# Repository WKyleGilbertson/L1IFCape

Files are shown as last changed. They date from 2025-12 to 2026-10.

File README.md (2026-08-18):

L1IFCape

===

This project (hardware and software) is licensed under CERN-OHL-S and GPLv3 for open-source, academic, and personal use. Commercial licensing is available. If you wish to integrate this receiver into a closed-source, proprietary, or commercial product without the reciprocal open-source obligations, please email contact@navstargps.us to purchase a commercial license.

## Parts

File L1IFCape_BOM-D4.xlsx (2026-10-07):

Reference | Qty | Value | Footprint | DNP | MFR | MP | MPN | VPN | Vendor | Description
C1 | 1 | 1F | L1IF:KR5R5C105R |  | Eaton | KW-5R5C334-R | KR-5R5C105-R | 283-KR-5R5C105-R-ND | DigiKey | Supercapacitors / Ultracapacitors CAP 0.33F 5.5V EDLC Coin Cell Cylind
C2,C3,C6,C7,C15,C27,C28,C35 | 8 | 1.0 uF | L1IF:C_0603_1608Metric |  | Murata |  | GCM188R71C105KA64D | 490-5241-1-ND | DigiKey | CAP CER 1UF 16V X7R 0603
C4,C5,C13,C21,C22,C23,C24,C25,C26 | 9 | 100 nF | L1IF:C_0603_1608Metric |  | Kemet |  | C0603C104K5RACAUTO | 399-6856-1-ND | DigiKey | CAP CER 0.1UF 50V X7R 0603
C8,C9,C14 | 3 | 10 nF | L1IF:C_0603_1608Metric |  | Kemet |  | C0603C103F3GECAUTO | 399-C0603C103F3GECAUTOCT-ND | DigiKey | CAP CER 10000PF 25V C0G/NP0 0603
C10,C11,C18 | 3 | 470 pF | L1IF:C_0603_1608Metric |  | Murata |  | GCM1885C2A471FA16D | 490-GCM1885C2A471FA16DCT-ND | DigiKey | CAP CER 470PF 100V C0G/NP0 0603
C12,C16,C20,C36,C37,C38,C39 | 7 | 100 pF | L1IF:C_0603_1608Metric |  | Murata |  | GCM1885C2A101FA16D | 490-GCM1885C2A101FA16DCT-ND | DigiKey | CAP CER 100PF 100V C0G/NP0 0603
C17 | 1 | 27 pF | L1IF:C_0603_1608Metric |  | Kemet |  | C0603C270F3HACAUTO | 399-C0603C270F3HACAUTOCT-ND | DigiKey | CAP CER 0603 27PF 25V ULTRA STAB
C19 | 1 | 470 pF | L1IF:C_0603_1608Metric | 470 pF | Murata |  | GCM1885C2A471FA16D | 490-GCM1885C2A471FA16DCT-ND | DigiKey | GCM1885C2A471FA16D
C29,C30 | 2 | 10 nF | L1IF:C_0603_1608Metric | 10 nF | Kemet |  | C0603C103F3GECAUTO | 399-C0603C103F3GECAUTOCT-ND | DigiKey | CAP CER 10000PF 25V C0G/NP0 0603
C31,C33 | 2 | 4.7 uF | L1IF:C_0805_2012Metric |  | Kemet |  | C0805C475J8RACAUTO | 399-15708-1-ND | DigiKey | CAP CER 4.7UF 10V X7R 0805
C32,C34 | 2 | 100 nF | L1IF:C_0805_2012Metric |  | Kemet |  | C0805C104K8RACTU | 399-C0805C104K8RACTUCT-ND | DigiKey | CAP CER 0.1UF 10V X7R 0805
D1,D2 | 2 | TPD1E01B04 | L1IF:Texas_DPY0002A_0.6x1mm_P0.65mm |  | Texas Instruments |  | TPD1E01B04DPYRQ1 | 296-TPD1E01B04DPYRQ1CT-ND | DigiKey | TPD1E01B04 Single-Channel ESD Protection Diode
FB1,FB2 | 2 | Ferrite_Bead | L1IF:C_0805_2012Metric |  | Murata |  | BLM21AG102SZ1D | 490-14399-1-ND | DigiKey | FERRITE BEAD 1 KOHM 0805 1LN
J1 | 1 | RF_Shield_One_Piece | L1IF:Laird_Technologies_BMI-S-103_26.21x26.21mm |  | Laird |  | BMI-S-103 | 903-1008-1-ND | DigiKey | One-piece EMI RF shielding cabinet
J2 | 1 | SMA | L1IF:SMA_Amphenol_901-143_Horizontal |  | Amphenol RF |  | 901-143 | ARF1206-ND | DigiKey | coaxial connector (BNC, SMA, SMB, SMC, Cinch/RCA, ...)
J3 | 1 | MMCX | L1IF:MMCX_Molex_73415-1471_Vertical |  | Amphenol RF |  | 908-22106 | ARF1904-ND | DigiKey | CONN MMCX JACK STR 50 OHM PCB
L1 | 1 | 33 nH | L1IF:L_0603_1608Metric |  |  |  | LQG18HH33NJ00D | 490-14837-1-ND | DigiKey | FIXED IND 33NH 500MA 0.54OHM SMD
P8,P9 | 2 | BeagleBone_Black_Header | L1IF:PinHeader_2x23_P2.54mm_Vertical |  | Samtec Inc. |  | SSQ-123-23-G-D | 612-SSQ-123-23-G-D-ND | DigiKey | CONN RCPT 46POS 0.1 GOLD PCB
R1,R3,R4,R6,R15 | 5 | 0 | L1IF:R_0603_1608Metric |  | Panasonic |  | ERJ-3GEY0R00V | P0.0GCT-ND | DigiKey | RES SMD 0 OHM JUMPER 1/10W 0603
R2,R5,R16 | 3 | 0 | L1IF:R_0603_1608Metric | 0 | Panasonic |  | ERJ-3GEY0R00V | P0.0GCT-ND | DigiKey | RES SMD 0 OHM JUMPER 1/10W 0603
R7,R8,R9,R11,R12,R18,R19,R20,R21,R22 | 10 | 33 | L1IF:R_0603_1608Metric |  | Panasonic |  | ERJ-3EKF33R0V | P33.0HCT-ND | Digikey | RES SMD 33 OHM 1% 1/10W 0603
R10 | 1 | 20k | L1IF:R_0603_1608Metric |  | Panasonic |  | ERJ-3EKF2002V | P20.0KHCT-ND | DigiKey | RES SMD 20K OHM 1% 1/10W 0603
R13,R14 | 2 | 2k | L1IF:R_0603_1608Metric |  | Panasonic |  | ERJ-3EKF2001V | P2.00KHCT-ND | DigiKey | RES SMD 2K OHM 1% 1/10W 0603
R17 | 1 | 10k | L1IF:R_0603_1608Metric |  | Panasonic |  | ERJ-3EKF1002V | P10.0KHCT-ND | DigiKey | RES SMD 10K OHM 1% 1/10W 0603
TP1 | 1 | ANTFLAG | L1IF:TestPoint_THTPad_D1.5mm_Drill0.7mm |  |  |  |  |  |  | test point
TP2 | 1 | LD | L1IF:TestPoint_THTPad_D1.5mm_Drill0.7mm |  |  |  |  |  |  | test point
TP3 | 1 | ~{SHDN} | L1IF:TestPoint_THTPad_D1.5mm_Drill0.7mm |  |  |  |  |  |  | test point
TP4 | 1 | CP | L1IF:TestPoint_Pad_D1.0mm |  |  |  |  |  |  | test point
TP5 | 1 | BBClk | L1IF:TestPoint_THTPad_D1.5mm_Drill0.7mm |  |  |  |  |  |  | test point
U1 | 1 | 24CS256 | L1IF:SOT-23-5 |  | Microchip Technology |  | 24CS256T-I/OT | 150-24CS256T-I/OTCT-ND | DigiKey | IC EEPROM 256KBIT I2C SOT23-5
U2 | 1 | MAX2769BETI+T | L1IF:QFN-28_EP_5.63x5.63_Pitch0.5mm |  | Maxim / Analog |  | MAX2769BETI/V+T | 175-MAX2769BETI/V+TCT-ND | DigiKey | RF RCVR GPS 1575.42MHZ 28TQFN
U3 | 1 | MAX31343ETAY+T | L1IF:MAX31343_TDFN |  | Maxim / Analog |  | MAX31343ETAY+T | 175-MAX31343ETAY+TCT-ND | DigiKey | ACCURATE/ROBUST RTC WITH INTEGRA
U4,U5 | 2 | TPS717285DCK | L1IF:TPS717285DCK |  | Texas Instruments |  | TPS717285DCK | 296-32541-1-ND | DigiKey | IC REG LINEAR 2.85V 150MA SC70-5
X1 | 1 | SIT5155 | L1IF:10L_CQFN |  | SiTime |  | SiT5155AICFKG28IT-16.367667 |  | SiTime | MEMS OSC DCTCXO 16.367667 MHZ
X2 | 1 | QPQ1060 | L1IF:QPQ1060_1.4x1.2 |  | Qorvo |  | QPQ1060SR | 2312-QPQ1060SRCT-ND | DigiKey | Bandpass Filter, 1090MHz, SAW filter 6-pin

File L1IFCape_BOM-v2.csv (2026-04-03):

Reference | Value | Datasheet | Footprint | Qty | DNP | MFR | MPN | Manufacturer | Vendor | Vendor PN | VPN
C1 | 1F | https://www.eaton.com/content/dam/eaton/products/electronic-components/resources/data-sheet/eaton-kr-supercapacitors-coin-cells-data-sheet.pdf | L1IF:KR5R5C105R | 1 |  | Eaton | KR-5R5C105-R | Eaton | DigiKey | 283-KR-5R5C105-R-ND | 283-KR-5R5C105-R-ND
C2,C3,C6,C7,C15,C27,C28,C35 | 1.0 uF |  | L1IF:C_0603_1608Metric | 8 |  |  | GCM188R71C105KA64D | Murata | DigiKey | 490-5241-1-ND
C4,C5,C13,C21,C22,C23,C24,C25,C26 | 100 nF |  | L1IF:C_0603_1608Metric | 9 |  |  | C0603C104K5RACAUTO | Kemet | DigiKey | 399-6856-1-ND
C8,C9,C14,C16 | 10 nF |  | L1IF:C_0603_1608Metric | 4 |  |  | C0603C103F3GECAUTO | Kemet | DigiKey | 399-C0603C103F3GECAUTOCT-ND
C10,C11,C18 | 470 pF |  | L1IF:C_0603_1608Metric | 3 |  |  | GCM1885C2A471FA16D | Murata | DigiKey | 490-GCM1885C2A471FA16DCT-ND
C12,C20 | 100 pF |  | L1IF:C_0603_1608Metric | 2 |  |  | GCM1885C2A101FA16D | Murata | DigiKey | 490-GCM1885C2A101FA16DCT-ND
C17 | 27 pF |  | L1IF:C_0603_1608Metric | 1 |  |  | C0603C270F3HACAUTO | Kemet | DigiKey | 399-C0603C270F3HACAUTOCT-ND
C19 | NL |  | L1IF:C_0603_1608Metric | 1 | 470 pF |  | GCM1885C2A471FA16D | Murata | DigiKey | 490-GCM1885C2A471FA16DCT-ND
C29,C30 | NL |  | L1IF:C_0603_1608Metric | 2 | 10 nF
C31,C33 | 4.7 uF |  | L1IF:C_0805_2012Metric | 2 |  |  | C0805C475J8RACAUTO | Kemet | DigiKey | 399-15708-1-ND
C32,C34 | 100 nF |  | L1IF:C_0805_2012Metric | 2 |  |  | C0805C104K8RACTU | Kemet | DigiKey | 399-C0805C104K8RACTUCT-ND
D1,D2 | TPD1E01B04 | https://www.ti.com/product/TPD1E01B04 | L1IF:Texas_DPY0002A_0.6x1mm_P0.65mm | 2 |  | Texas Instruments | TPD1E01B04DPYRQ1 | Texas Instruments | DigiKey | 296-TPD1E01B04DPYRQ1CT-ND | 296-TPD1E01B04DPYRQ1CT-ND
FB1,FB2 | Ferrite_Bead | https://www.murata.com/en-us/products/en-us/products/productdata/8796749987870/QNFA9114.pdf | L1IF:C_0805_2012Metric | 2 |  |  | BLM21AG102SZ1D | Murata Electronics | DigiKey | 490-14399-1-ND
J1 | RF_Shield_One_Piece |  | L1IF:Laird_Technologies_BMI-S-103_26.21x26.21mm | 1 |  |  | BMI-S-103 | Laird Technologies EMI | DigiKey | 903-1008-1-ND
J2 | SMA |  | L1IF:SMA_Amphenol_901-143_Horizontal | 1 |  | Amphenol RF | 901-143 |  | DigiKey | ARF1206-ND
J3 | MMCX |  | L1IF:MMCX_Molex_73415-1471_Vertical | 1 |  | Amphenol RF | 908-22106 |  | DigiKey | ARF1904-ND
L1 | 33 nH | https://search.murata.co.jp/Ceramy/image/img/P02/JELF243B-9102.pdf | L1IF:L_0603_1608Metric | 1 |  |  | LQG18HH33NJ00D | Murata Electronics | DigiKey | 490-14837-1-ND | 490-14837-1-ND
P8,P9 | BeagleBone_Black_Header | https://mm.digikey.com/Volume0/opasdata/d220001/medias/docus/6129/ssq-1xx-xx-xxx-x-xx-xxx-xx-x-mkt.pdf | L1IF:PinHeader_2x23_P2.54mm_Vertical | 2 |  | Samtec Inc. | SSQ-123-02-G-D |  | DigiKey | SAM1185-23-ND
R1 | 20k |  | L1IF:R_0603_1608Metric | 1 |  |  | ERJ-3EKF2002V | Panasonic | DigiKey | P20.0KHCT-ND
R2,R3 | 2k |  | L1IF:R_0603_1608Metric | 2 |  | Panasonic | ERJ-3EKF2001V |  | DigiKey | P2.00KHCT-ND | P2.00KHCT-ND
R4 | 0 |  | L1IF:R_0603_1608Metric | 1 |  | Panasonic | ERJ-3GEY0R00V |  | DigiKey | P0.0GCT-ND | P0.0GCT-ND
R5 | NL |  | L1IF:R_0603_1608Metric | 1 | 0 | Panasonic | ERJ-3GEY0R00V |  | DigiKey | P0.0GCT-ND | P0.0GCT-ND
R6,R7,R8,R9,R10 | 10k |  | L1IF:R_0603_1608Metric | 5 |  | Panasonic | ERJ-3EKF1002V |  | DigiKey | P10.0KHCT-ND
TP1 | ANTFLAG |  | L1IF:TestPoint_Pad_D1.0mm | 1
TP2 | LD |  | L1IF:TestPoint_Pad_D1.0mm | 1
TP3 | ~{SHDN} |  | L1IF:TestPoint_Pad_D1.0mm | 1
TP4 | CP |  | L1IF:TestPoint_Pad_D1.0mm | 1
U1 | 24CS256 | https://www.microchip.com/en-us/product/24cs256 | L1IF:SOT-23-5 | 1 |  | Microchip Technology | 24CS256T-I/OT | Microchip Technology | DigiKey | 150-24CS256T-I/OTCT-ND | 150-24CS256T-I/OTCT-ND
U2 | MAX2769BETI+T | https://www.analog.com/media/en/technical-documentation/data-sheets/MAX2769B.pdf | L1IF:QFN-28_EP_5.63x5.63_Pitch0.5mm | 1 |  | Maxim / Analog | MAX2769BETI/V+T | Maxim / Analog | DigiKey | 175-MAX2769BETI/V+TCT-ND | 175-MAX2769BETI/V+TCT-ND
U3 | MAX31343ETAY+T | https://www.analog.com/media/en/technical-documentation/data-sheets/MAX31343.pdf | L1IF:MAX31343_TDFN | 1 |  | Maxim / Analog | MAX31343ETAY+T | Maxim / Analog | DigiKey | 175-MAX31343ETAY+TCT-ND | 175-MAX31343ETAY+TCT-ND
U4,U5 | TPS717285DCK | https://www.ti.com/lit/ds/symlink/tps717.pdf | L1IF:TPS717285DCK | 2 |  | Texas Instruments | TPS717285DCK | Texas Instruments | DigiKey | 296-32541-1-ND | 296-32541-1-ND
U6 | DS90LV012A | https://www.ti.com/lit/gpn/ds90lv012a | L1IF:SOT-23-5 | 1 |  | Texas Instruments | DS90LV012ATMFX/NOPB | Texas Instruments | DigiKey | 296-38706-1-ND | 296-38706-1-ND
X1 | SIT5156 | https://www.sitime.com/support/resource-library/datasheets/sit5156-datasheet | L1IF:10L_CQFN | 1 |  | SiTime | SIT5156AICFK-30N0-16.368000 | SiTime | DigiKey | 1473-SIT5156AICFK-30N0-16.368000-ND | 1473-SIT5156AICFK-30N0-16.368000-ND
X2 | QPQ1060 | https://www.qorvo.com/products/p/QPQ1060 | L1IF:QPQ1060_1.4x1.2 | 1 |  | Qorvo | QPQ1060SR | Qorvo | DigiKey | 2312-QPQ1060SRCT-ND | 2312-QPQ1060SRCT-ND

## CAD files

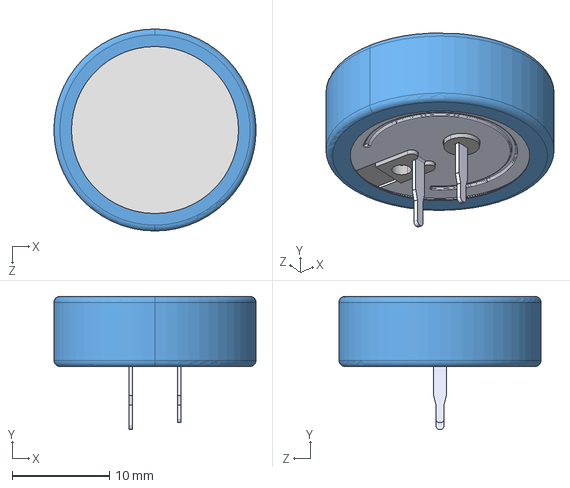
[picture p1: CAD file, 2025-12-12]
Parts/LIB_KR-5R5C105-R/KR-5R5C105-R/3D/KR-5R5C105-R.stp
20.8 x 13.7 x 20.8 mm

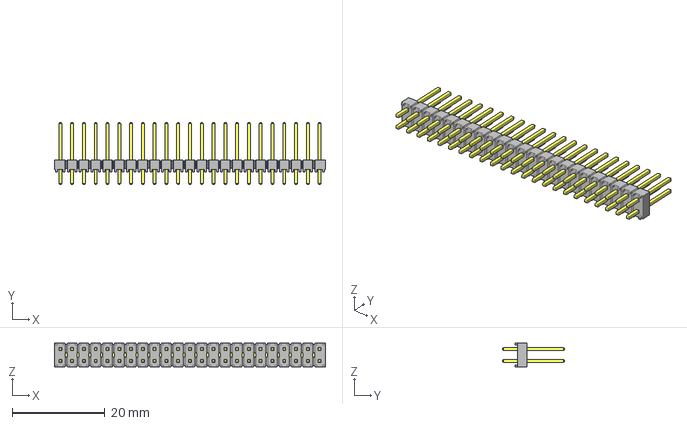
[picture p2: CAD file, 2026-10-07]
STEP/TSW-123-14-G-D.stp
58.4 x 13.5 x 5.08 mm
TSW-123-14-G-D_body
T-1S6-08-TSW-1-14-23-D

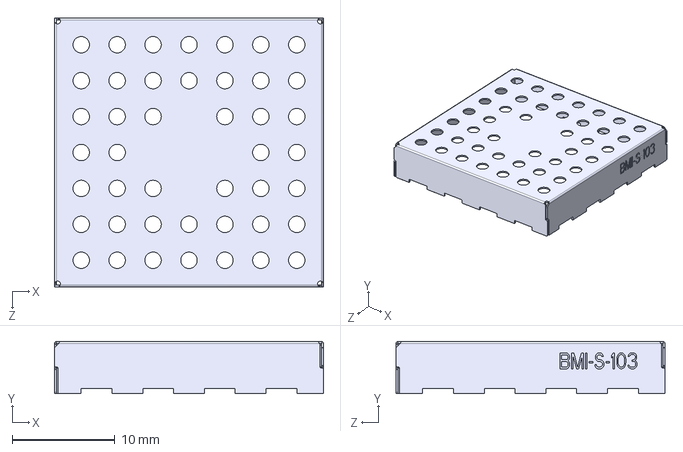
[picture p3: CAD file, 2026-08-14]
STEP/Laird-BMI-S-103-1.STEP
26.2 x 5.08 x 26.2 mm

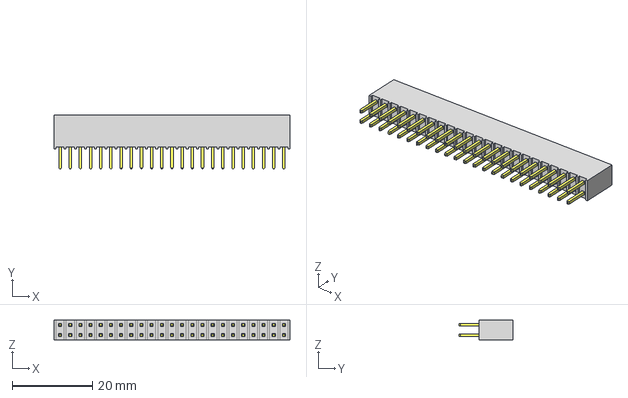
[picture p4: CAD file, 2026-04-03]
STEP/SSQ-123-02-G-D.stp
58.9 x 13.4 x 4.95 mm
T1SSQ-123-02-G-D
P2SSQ-123-02-G-D

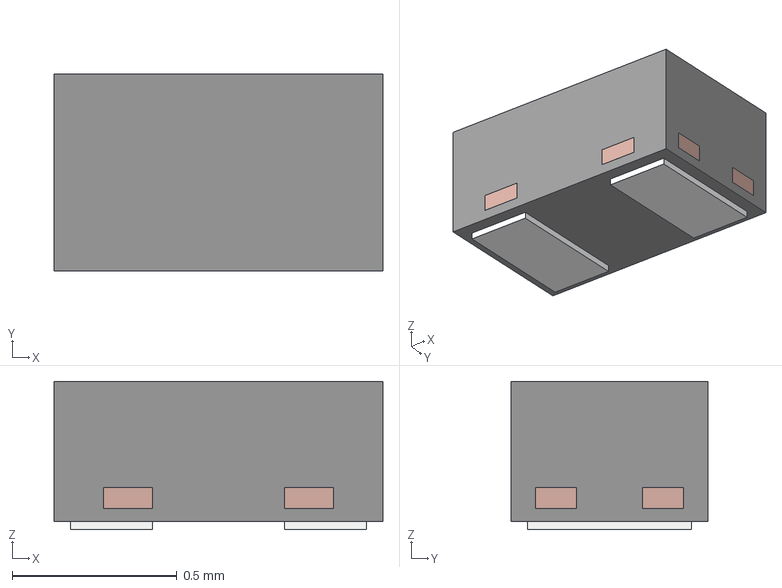
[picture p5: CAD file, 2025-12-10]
STEP/DPY0002A.stp
1.00 x 0.6 x 0.45 mm
BODY-SON
FRAME-DPY0002A

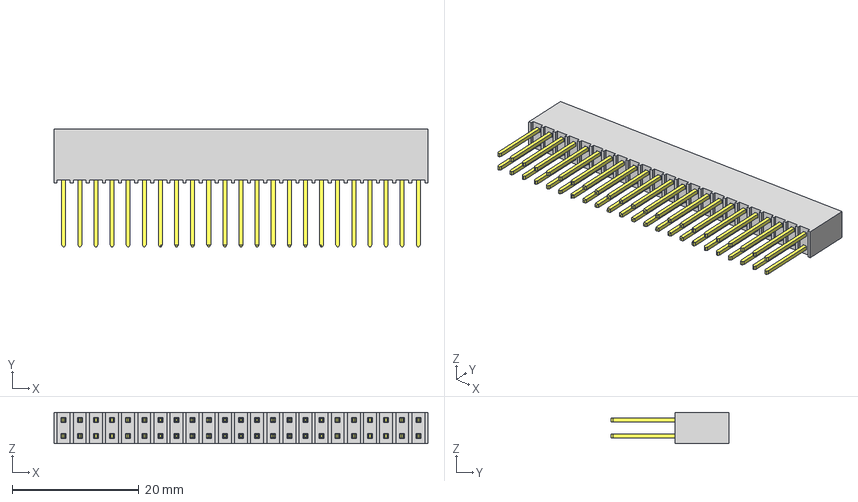
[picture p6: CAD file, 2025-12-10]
STEP/SSQ-123-03-G-D.stp
58.9 x 18.5 x 4.95 mm
T1SSQ-123-03-G-D
P2SSQ-123-03-G-D

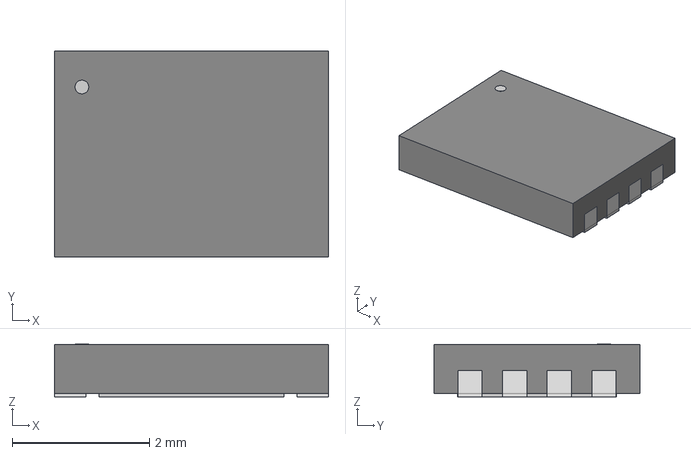
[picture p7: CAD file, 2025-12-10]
STEP/8-TDFN (3x4).step
3.99 x 3.00 x 0.765 mm

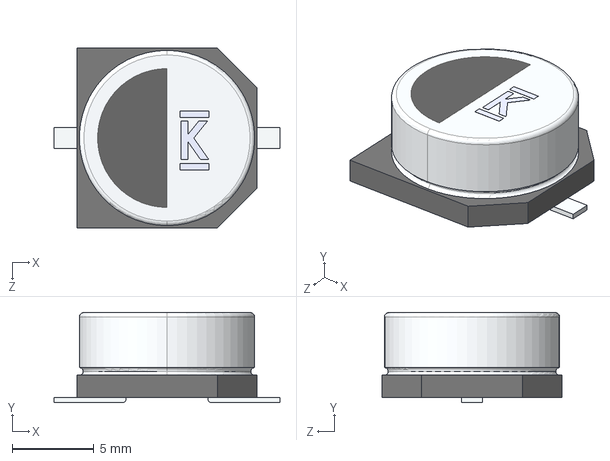
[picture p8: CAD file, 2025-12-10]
STEP/FCR0H104ZFTBR24.step
13.8 x 5.50 x 11.0 mm

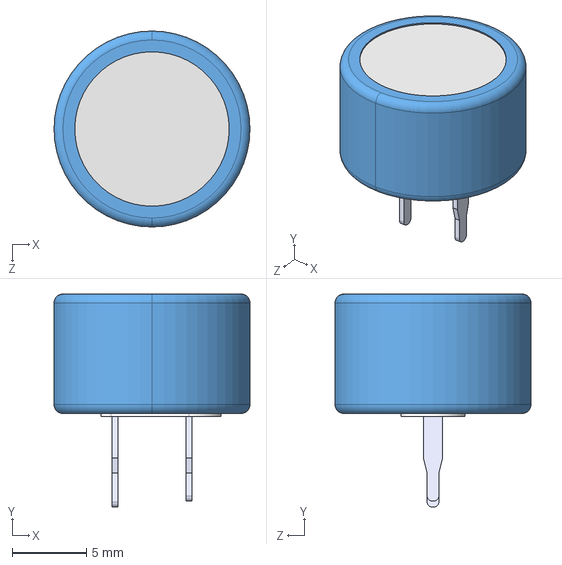
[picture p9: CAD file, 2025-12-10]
STEP/KW-5R5C334-R.stp
13.2 x 14.4 x 13.2 mm

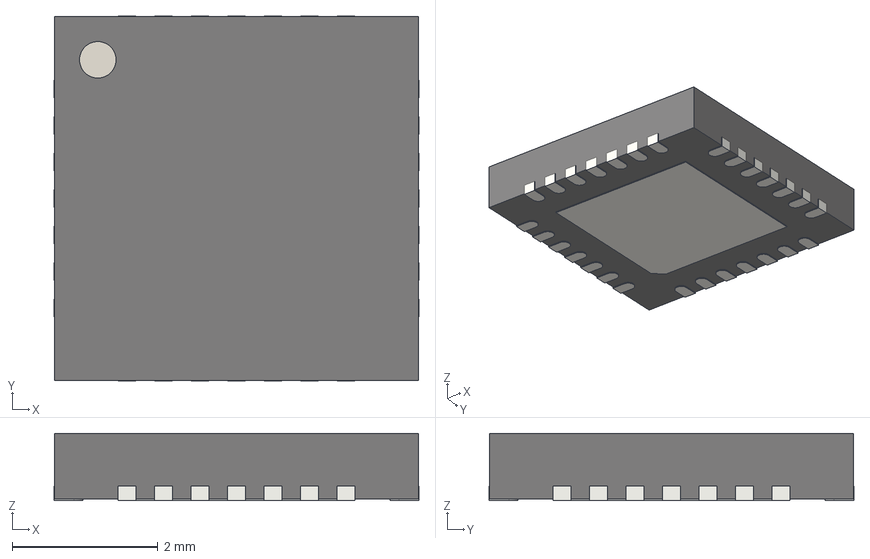
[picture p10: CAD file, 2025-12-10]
STEP/QFN-28-1EP_5x5mm_P0.5mm_EP3.35x3.35mm.step
5.00 x 5.00 x 0.92 mm

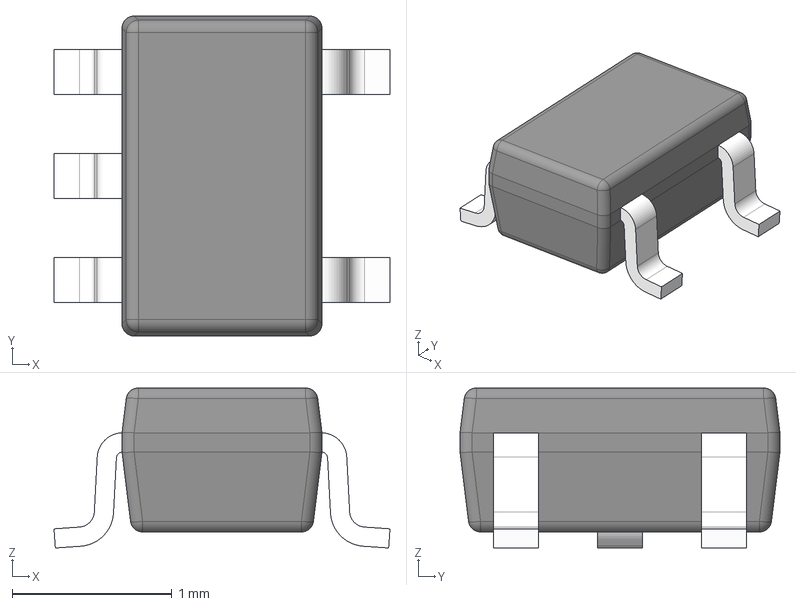
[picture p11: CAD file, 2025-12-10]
STEP/DCK0005A.stp
2.10 x 2.00 x 1.00 mm
BODY-SOT
LEAD-SOT x 5
PIN1-ID

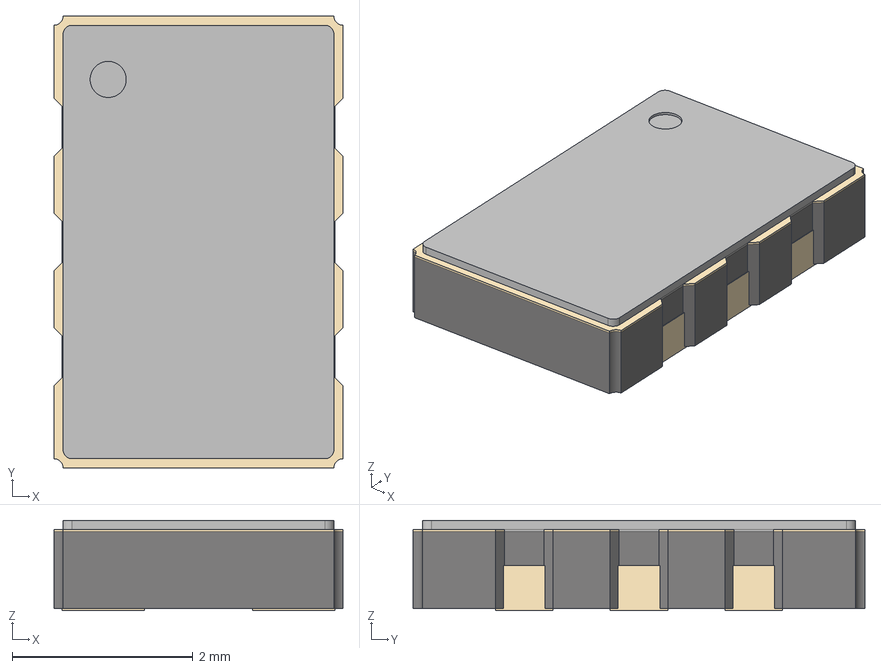
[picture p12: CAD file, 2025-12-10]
STEP/Oscillator_SMD_IDT_JS6-6_5.0x3.2mm_P1.27mm.step
3.20 x 5.00 x 1.00 mm

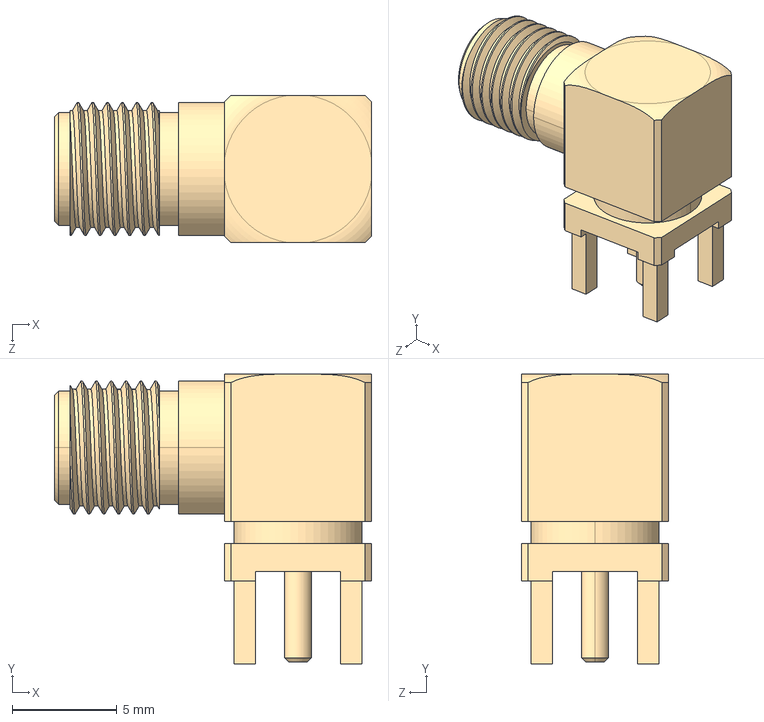
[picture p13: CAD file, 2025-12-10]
STEP/SMA-J-P-X-RA-TH1.step
15.1 x 13.8 x 7.00 mm

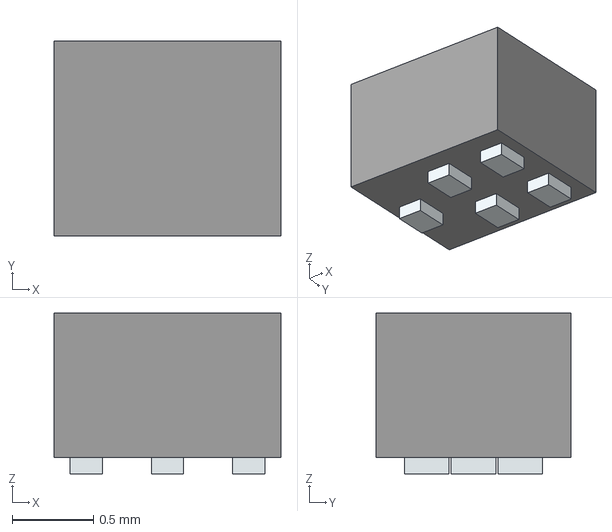
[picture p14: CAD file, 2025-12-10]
STEP/QPQ1060SR.stp
1.40 x 1.20 x 0.99 mm
Pins

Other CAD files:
Parts/LIB_KR-5R5C105-R/KR-5R5C105-R/Allegro/kr5r5c105r.psm
Parts/LIB_KR-5R5C105-R/KR-5R5C105-R/DEHDL/kr_5r5c105_r/chips/chips.prt

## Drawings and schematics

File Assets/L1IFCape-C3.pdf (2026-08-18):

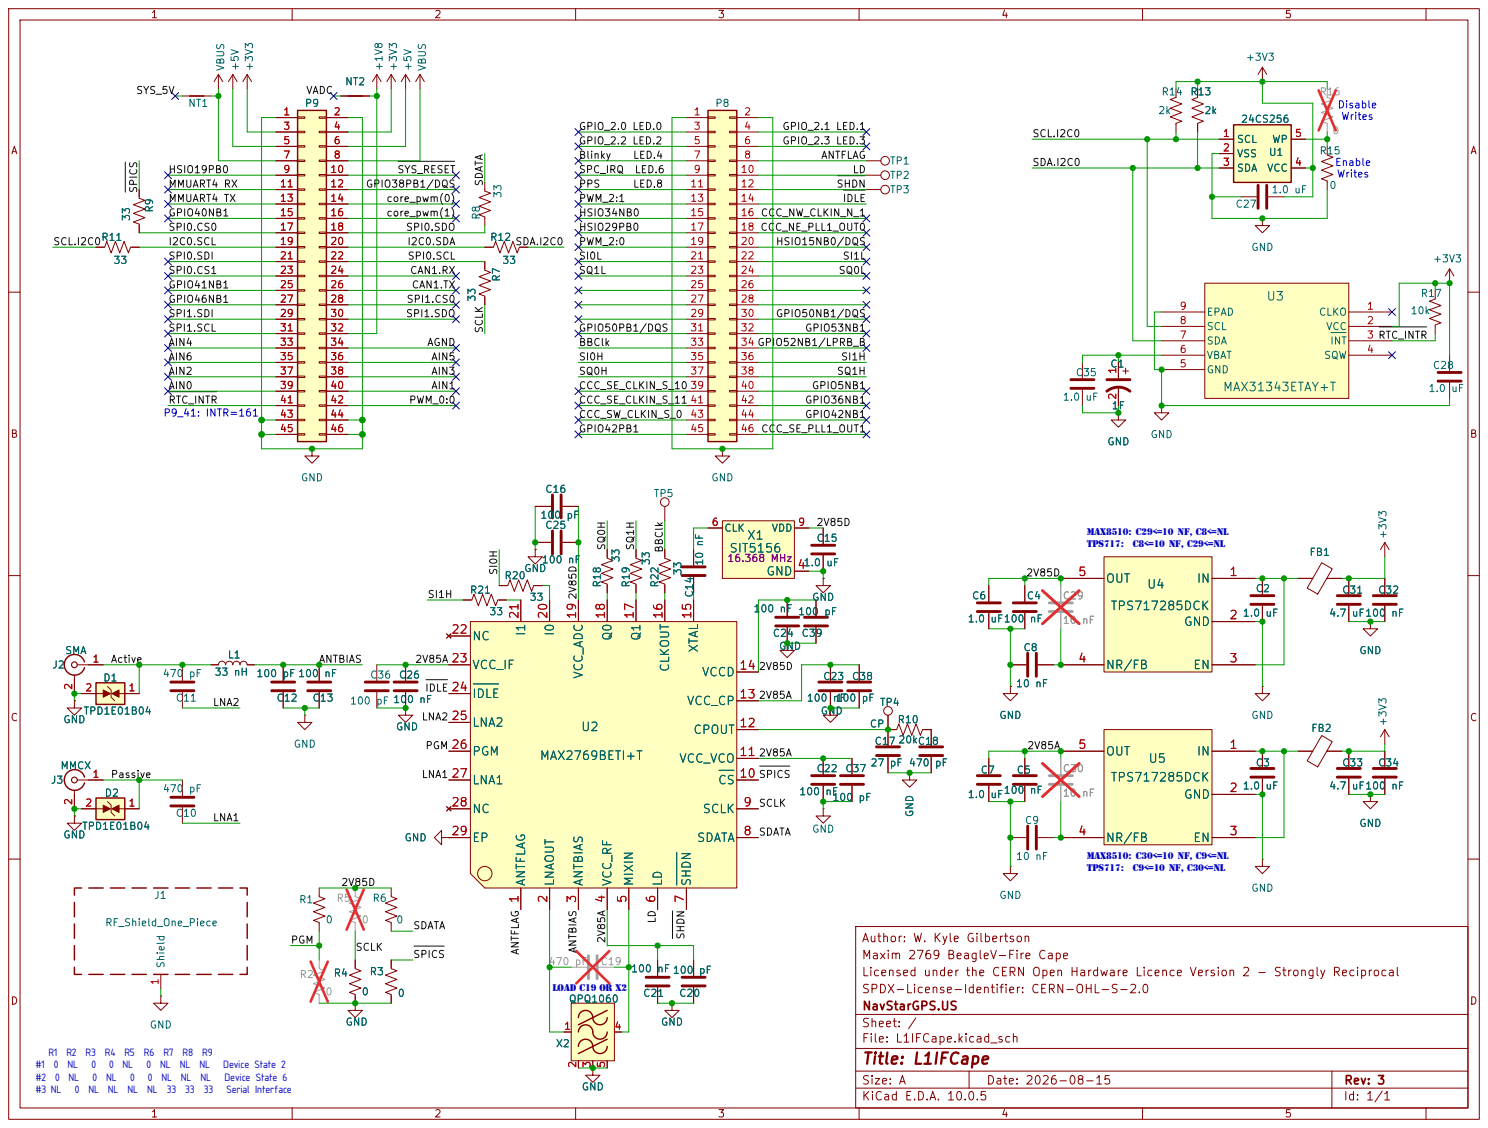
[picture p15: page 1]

3 3 | 4 4
5 5 | 6 6
7 7 | 8 8

Author: W. Kyle Gilbertson
Maxim 2769 BeagleV-Fire Cape
Licensed under the CERN Open Hardware Licence Version 2 - Strongly Reciprocal
SPDX-License-Identifier: CERN-OHL-S-2.0
NavStarGPS.US
Sheet: /
File: L1IFCape.kicad_sch
Title: L1IFCape

Size: A | Rev: 3
KiCad E.D.A. 10.0.5 | Id: 1/1

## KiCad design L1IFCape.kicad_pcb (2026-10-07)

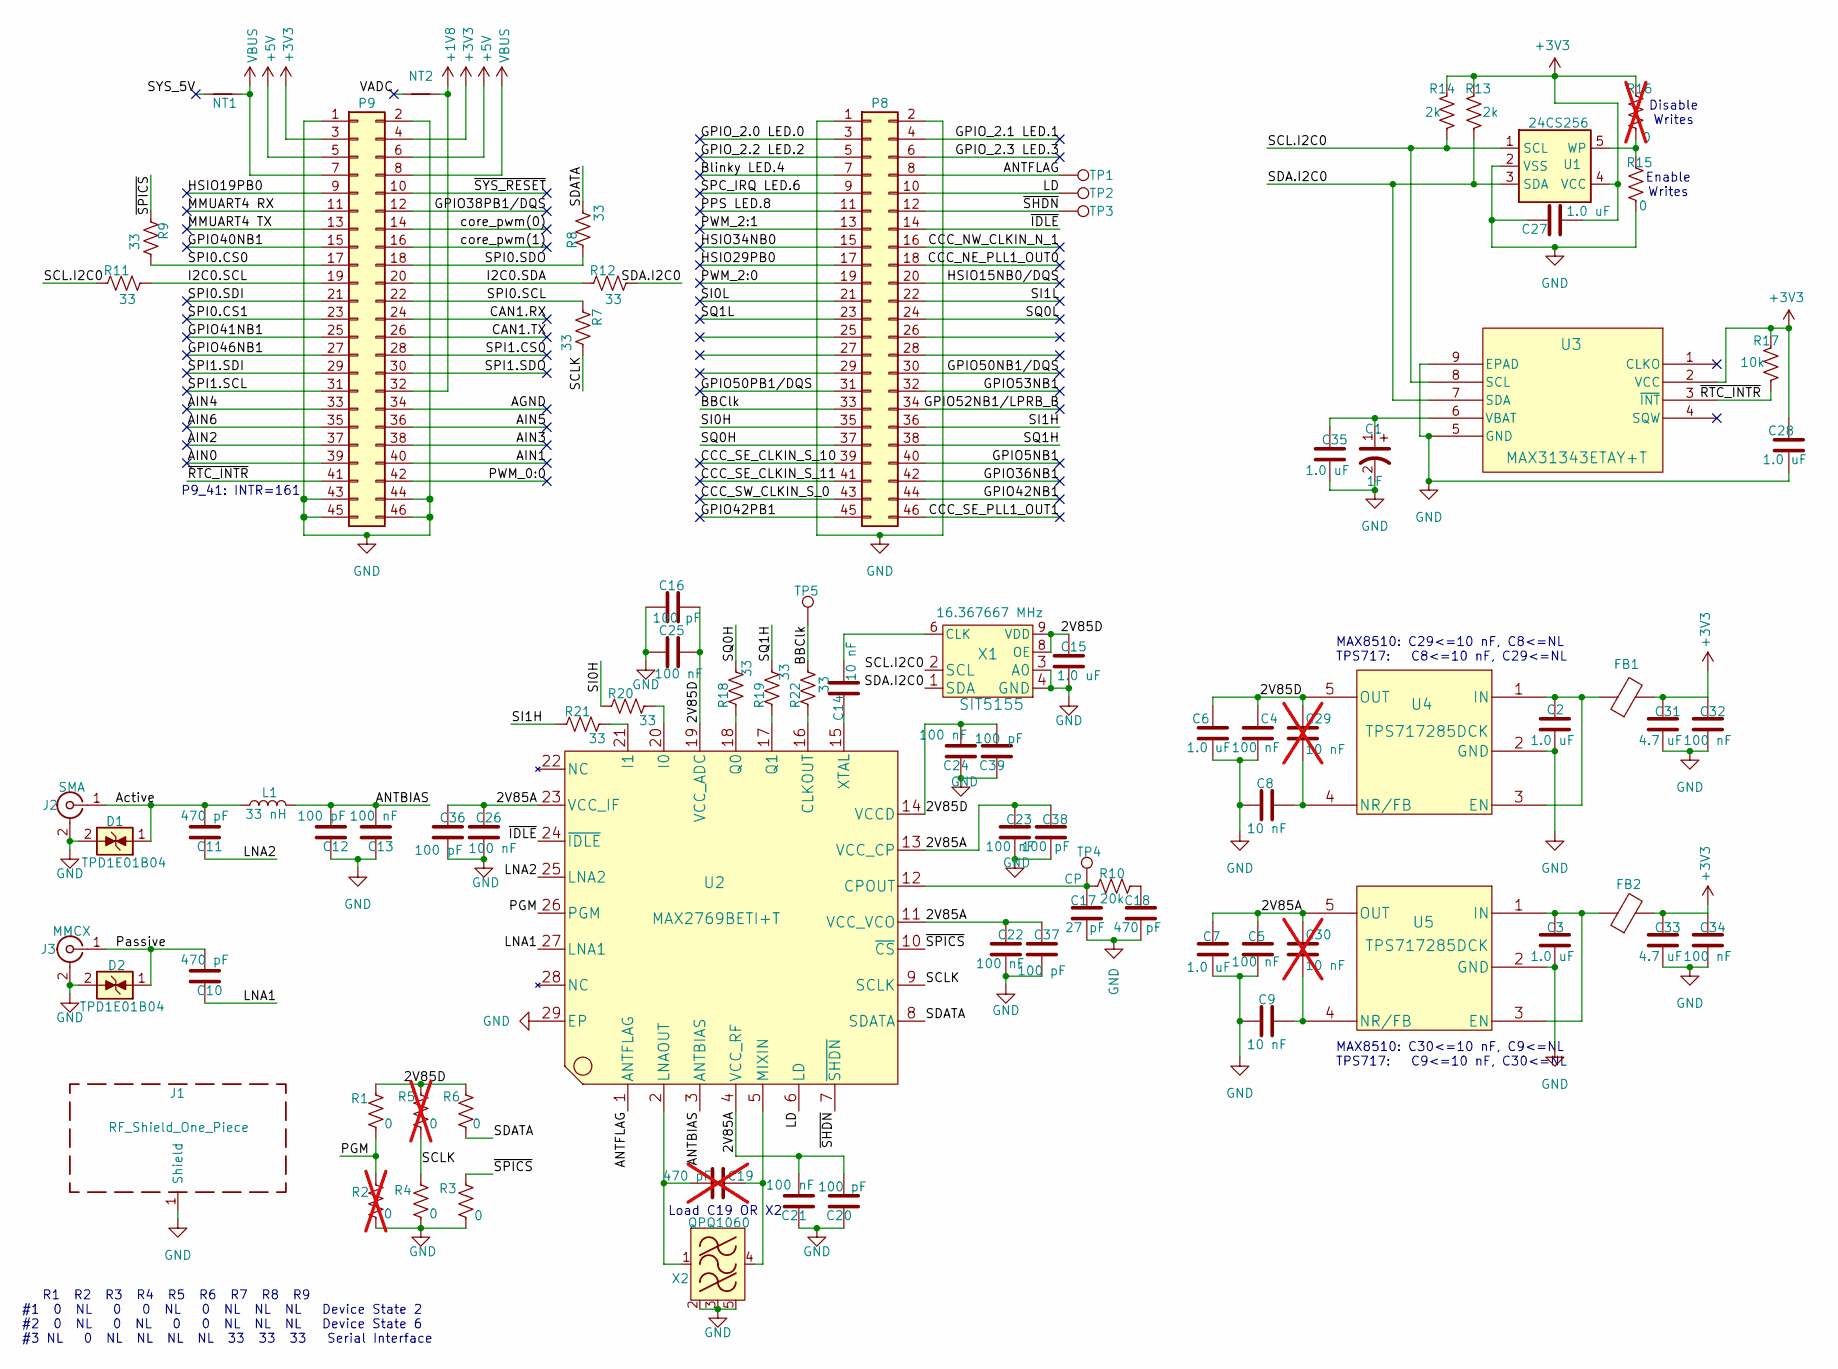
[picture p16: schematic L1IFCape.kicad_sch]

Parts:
C1: 1F; KR5R5C105R; MANUFACTURER_PART_NUMBER KW-5R5C334-R; MOUSER_PART_NUMBER 504-KW-5R5C334-R
C2, C3, C6, C7, C15, C27, C28, C35: 1.0 uF; C_0603_1608Metric; MPN GCM188R71C105KA64D
C4, C5, C13, C21, C22, C23, C24, C25, C26: 100 nF; C_0603_1608Metric; MPN C0603C104K5RACAUTO
C8, C9, C14: 10 nF; C_0603_1608Metric; MPN C0603C103F3GECAUTO
C10, C11, C18: 470 pF; C_0603_1608Metric; MPN GCM1885C2A471FA16D
C12, C16, C20, C36, C37, C38, C39: 100 pF; C_0603_1608Metric; MPN GCM1885C2A101FA16D
C17: 27 pF; C_0603_1608Metric; MPN C0603C270F3HACAUTO
C19: 470 pF; C_0603_1608Metric; MPN GCM1885C2A471FA16D; not fitted
C29, C30: 10 nF; C_0603_1608Metric; MPN C0603C103F3GECAUTO; not fitted
C31, C33: 4.7 uF; C_0805_2012Metric; MPN C0805C475J8RACAUTO
C32, C34: 100 nF; C_0805_2012Metric; MPN C0805C104K8RACTU
D1, D2: TPD1E01B04; Texas_DPY0002A_0.6x1mm_P0.65mm; MPN TPD1E01B04DPYRQ1
FB1, FB2: Ferrite_Bead; C_0805_2012Metric; MPN BLM21AG102SZ1D
J1: RF_Shield_One_Piece; Laird_Technologies_BMI-S-103_26.21x26.21mm; MPN BMI-S-103
J2: SMA; SMA_Amphenol_901-143_Horizontal; MPN 901-143
J3: MMCX; MMCX_Molex_73415-1471_Vertical; MPN 908-22106
L1: 33 nH; L_0603_1608Metric; MPN LQG18HH33NJ00D
NT1, NT2: NetTie_2
P8, P9: BeagleBone_Black_Header; PinHeader_2x23_P2.54mm_Vertical; MPN SSQ-123-23-G-D
R1, R3, R4, R6, R15: 0; R_0603_1608Metric; MPN ERJ-3GEY0R00V
R2, R5, R16: 0; R_0603_1608Metric; MPN ERJ-3GEY0R00V; not fitted
R7, R8, R9, R11, R12, R18, R19, R20, R21, R22: 33; R_0603_1608Metric; MPN ERJ-3EKF33R0V
R10: 20k; R_0603_1608Metric; MPN ERJ-3EKF2002V
R13, R14: 2k; R_0603_1608Metric; MPN ERJ-3EKF2001V
R17: 10k; R_0603_1608Metric; MPN ERJ-3EKF1002V
TP1: ANTFLAG; TestPoint_THTPad_D1.5mm_Drill0.7mm
TP2: LD; TestPoint_THTPad_D1.5mm_Drill0.7mm
TP3: ~{SHDN}; TestPoint_THTPad_D1.5mm_Drill0.7mm
TP4: CP; TestPoint_Pad_D1.0mm
TP5: BBClk; TestPoint_THTPad_D1.5mm_Drill0.7mm
U1: 24CS256; SOT-23-5; MPN 24CS256T-I/OT
U2: MAX2769BETI+T; QFN-28_EP_5.63x5.63_Pitch0.5mm; MPN MAX2769BETI/V+T
U3: MAX31343ETAY+T; MAX31343_TDFN; MPN MAX31343ETAY+T
U4, U5: TPS717285DCK; MPN TPS717285DCK
X1: SIT5155; 10L_CQFN; MPN SiT5155AICFKG28IT-16.367667
X2: QPQ1060; QPQ1060_1.4x1.2; MPN QPQ1060SR

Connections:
+1V8: NT2.2, P9.32
+3V3: C27.1, C28.1, C31.1, C32.1, C33.1, C34.1, FB1.2, FB2.2, P9.3, P9.4, R13.1, R14.1, R16.2, R17.1, U1.4 (VCC), U3.2 (VCC)
+5V: P9.5, P9.6
/2V85A: C5.1, C7.1, C20.2, C21.2, C22.1, C23.2, C26.1, C30.1, C36.1, C37.1, C38.2, U2.4 (VCC_RF), U2.11 (VCC_VCO), U2.13 (VCC_CP), U2.23 (VCC_IF), U5.5 (OUT)
/AGND: P9.34
/AIN0: P9.39
/AIN1: P9.40
/AIN2: P9.37
/AIN3: P9.38
/AIN4: P9.33
/AIN5: P9.36
/AIN6: P9.35
/ANTBIAS: C12.2, C13.2, L1.1, U2.3 (ANTBIAS)
/ANTFLAG: P8.8, TP1.1 (1_1), U2.1 (ANTFLAG)
/Active: C11.2, D1.1 (K), J2.1 (In), L1.2
/BBClk: P8.33, R22.2, TP5.1 (1_1)
/Blinky LED.4: P8.7
/CAN1.RX: P9.24
/CAN1.TX: P9.26
/CCC_NE_PLL1_OUT0: P8.18
/CCC_NW_CLKIN_N_1: P8.16
/CCC_SE_CLKIN_S_10: P8.39
/CCC_SE_CLKIN_S_11: P8.41
/CCC_SE_PLL1_OUT1: P8.46
/CCC_SW_CLKIN_S_0: P8.43
/GPIO5NB1: P8.40
/GPIO36NB1: P8.42
/GPIO38PB1/DQS: P9.12
/GPIO40NB1: P9.15
/GPIO41NB1: P9.25
/GPIO42NB1: P8.44
/GPIO42PB1: P8.45
/GPIO46NB1: P9.27
/GPIO50NB1/DQS: P8.30
/GPIO50PB1/DQS: P8.31
/GPIO52NB1/LPRB_B: P8.34
/GPIO53NB1: P8.32
/GPIO_2.0 LED.0: P8.3
/GPIO_2.1 LED.1: P8.4
/GPIO_2.2 LED.2: P8.5
/GPIO_2.3 LED.3: P8.6
/HSIO15NB0/DQS: P8.20
/HSIO19PB0: P9.9
/HSIO29PB0: P8.17
/HSIO34NB0: P8.15
/I2C0.SCL: P9.19, R11.2
/I2C0.SDA: P9.20, R12.1
/LD: P8.10, TP2.1 (1_1), U2.6 (LD)
/LNA1: C10.1, U2.27 (LNA1)
/LNA2: C11.1, U2.25 (LNA2)
/MMUART4 RX: P9.11
/MMUART4 TX: P9.13
/PGM: R1.2, R2.1, U2.26 (PGM)
/PPS LED.8: P8.11
/PWM_0:0: P9.42
/PWM_2:0: P8.19
/PWM_2:1: P8.13
/Passive: C10.2, D2.1 (K), J3.1 (In)
/SCL.I2C0: R11.1, R14.2, U1.1 (SCL), U3.8 (SCL), X1.2 (SCL)
/SCLK: R4.2, R5.2, R7.2, U2.9 (SCLK)
/SDATA: R6.2, R8.2, U2.8 (SDATA)
/SI0H: P8.35, R20.1
/SI0L: P8.21
/SI1H: P8.36, R21.2
/SI1L: P8.22
/SPC_IRQ LED.6: P8.9
/SPI0.CS0: P9.17, R9.2
/SPI0.CS1: P9.23
/SPI0.SCL: P9.22, R7.1
/SPI0.SDI: P9.21
/SPI0.SDO: P9.18, R8.1
/SPI1.CS0: P9.28
/SPI1.SCL: P9.31
/SPI1.SDI: P9.29
/SPI1.SDO: P9.30
/SQ0H: P8.37, R18.2
/SQ0L: P8.24
/SQ1H: P8.38, R19.2
/SQ1L: P8.23
/core_pwm(0): P9.14
/core_pwm(1): P9.16
/~IDLE: P8.14, U2.24 (~IDLE)
/~RTC_INTR: P9.41, R17.2, U3.3 (~INT)
/~SHDN: P8.12, TP3.1 (1_1), U2.7 (~SHDN)
/~SPICS: R3.2, R9.1, U2.10 (~CS)
/~SYS_RESET: P9.10
GND: C1.2, C2.2, C3.2, C4.2, C5.2, C6.2, C7.2, C8.1, C9.1, C12.1, C13.1, C15.2, C16.1, C17.2, C18.2, C20.1, C21.1, C22.2, C23.1, C24.1, C25.1, C26.2, C27.2, C28.2, C31.2, C32.2, C33.2, C34.2, C35.2, C36.2, C37.2, C38.1, C39.1, D1.2 (A), D2.2 (A), J1.1 (Shield_1), J2.2 (Ext), J3.2 (Ext), P8.1, P8.2, P9.1, P9.2, P9.43, P9.44, P9.45, P9.46, R2.2, R3.1, R4.1, R15.1, U1.2 (VSS), U2.29 (EP), U3.5 (GND), U3.9 (EPAD), U4.2 (GND), U5.2 (GND), X1.3 (A0), X1.4 (GND), X1.5 (A0), X2.2 (GND), X2.3 (GND), X2.5 (GND); also elsewhere on the board
unnamed: C18.1, R10.2
unnamed: R15.2, R16.1, U1.5 (WP)
unnamed: R22.1, U2.16 (CLKOUT)
unnamed: C17.1, R10.1, TP4.1 (1_1), U2.12 (CPOUT)
unnamed: R20.2, U2.20 (I0)
unnamed: R21.1, U2.21 (I1)
unnamed: C19.2, U2.2 (LNAOUT), X2.1 (IN)
unnamed: C19.1, U2.5 (MIXIN), X2.4 (OUT)
unnamed: R18.1, U2.18 (Q0)
unnamed: R19.1, U2.17 (Q1)
unnamed: C14.2, U2.15 (XTAL)
unnamed: C1.1, C35.1, U3.6 (VBAT)
unnamed: C2.1, FB1.1, U4.1 (IN), U4.3 (EN)
unnamed: C8.2, C29.2, U4.4 (NR/FB)
unnamed: C3.1, FB2.1, U5.1 (IN), U5.3 (EN)
unnamed: C9.2, C30.2, U5.4 (NR/FB)
unnamed: C14.1, X1.6 (CLK)
VBUS: NT1.2, P9.7, P9.8

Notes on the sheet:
R1 R2 R3 R4 R5 R6 R7 R8 R9 #1 0 NL 0 0 NL 0 NL NL NL Device State 2 #2 0 NL 0 NL 0 0 NL NL NL Device State 6 #3 NL 0 NL NL NL NL 33 33 33 Serial Interface
Disable Writes
Load C19 OR X2
MAX8510: C29<=10 nF, C8<=NL TPS717: C8<=10 nF, C29<=NL
MAX8510: C30<=10 nF, C9<=NL TPS717: C9<=10 nF, C30<=NL
P9_41: INTR=161
Enable Writes

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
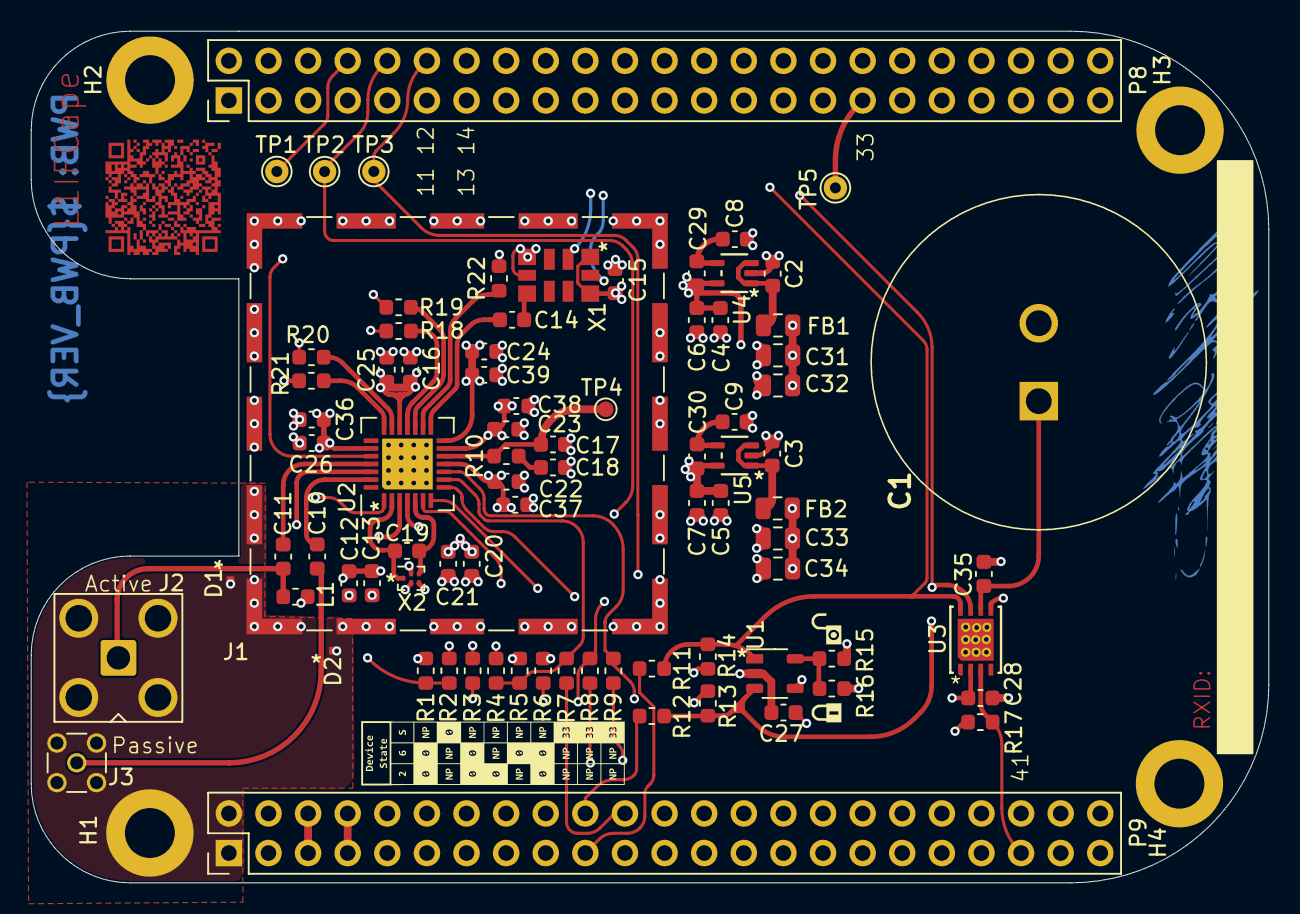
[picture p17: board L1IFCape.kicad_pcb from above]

Board: 4 copper layers, 79.4 x 54.6 mm, 88 parts (0 on the bottom side), 49 nets.

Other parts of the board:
H1, H2, H3, H4: MountingHole_3.2mm_M3_DIN965_Pad
QR*****: QR-L1IFCape-8mm

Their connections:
GND: H1.1, H2.1, H3.1, H4.1; also elsewhere on the board

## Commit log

2025-12-09 Added Design Files
    [L1IFCape.kicad_pcb, L1IFCape.kicad_sch]
2025-12-10 Added CERN License
    [8-TDFN (3x4).step, DCK0005A.stp, DPY0002A.stp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]
2025-12-10 Moved some parts around
    [L1IFCape.kicad_pcb]
2025-12-12 Added Padlock graphic and 1F Supercap
    [EDI2CAP.CFG, KR-5R5C105-R.SchLib, KR-5R5C105-R.stp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]
2026-03-05 Shorter Header Pins
    [L1IFCape.kicad_sch]
2026-04-03 Ordered Rev2 from OSH Park
    [L1IFCape.kicad_pcb, L1IFCape.kicad_sch, L1IFCape_BOM-v2.csv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]
2026-05-22 Moved Antenna Ports, and changed resistor bias circuit
    [L1IFCape.kicad_pcb, L1IFCape.kicad_sch]
2026-08-14 Version C3 ready for fabrication
    [L1IFCape.kicad_pcb, L1IFCape.kicad_sch, Laird-BMI-S-103-1.STEP]
2026-08-15 Device State Table Fixed
2026-08-15 Cleaned up for fabrication
    [L1IFCape.kicad_pcb, L1IFCape.kicad_sch]
2026-08-15 Sent out for quotes
    [L1IFCape-B_Cu.gbl, L1IFCape-B_Mask.gbr, L1IFCape-Edge_Cuts.gbr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]
2026-08-16 Tented Vias on MAX2769 and MAX31343 Bottom Layer
    [L1IFCape-B_Cu.gbr, L1IFCape-B_Mask.gbr, L1IFCape-Edge_Cuts.gbr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]
2026-08-16 Made Assembly Drawing
    [L1IFCape.kicad_pcb]
2026-08-16 Creating BOM
    [DeviceState.xlsx, L1IFCape.kicad_sch]
2026-08-17 Added schematic to the back and cleaned up some schematic issues
    [L1IFCape.kicad_pcb, L1IFCape.kicad_sch]
2026-08-17 Cleaned up BOM
    [L1IFCape.kicad_sch]
2026-08-17 Added Schematic Footprint
2026-08-17 Changed CERN license to strong
    [L1IFCape.kicad_pcb, L1IFCape.kicad_sch]
2026-08-18 Refreshed Fabrication Drawings
    [L1IFCape-B_Cu.gbr, L1IFCape-B_Mask.gbr, L1IFCape-B_Silkscreen.gbr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]
2026-08-18 Updated CERN License Wording
    [L1IFCape-B_Cu.gbr, L1IFCape-B_Mask.gbr, L1IFCape-B_Silkscreen.gbr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]
2026-09-01 Clipped EP corner at Pin 1
    [L1IFCape.kicad_pcb]
2026-10-06 Added I2C connection to SiT5156
    [L1IFCape.kicad_pcb, L1IFCape.kicad_pcb-1.kicad_pcb, L1IFCape.kicad_sch]
2026-10-07 SiT5156 Part Number...TBC
    [L1IFCape.kicad_sch]
2026-10-07 Updated Date to 2026-10-05 for Rev D4
    [L1IFCape.kicad_pcb, L1IFCape.kicad_sch]
2026-10-07 Clean up for manufacture of D4
    [DeviceState-ConsolasBold.xlsx, L1IFCape.kicad_pcb, L1IFCape.kicad_pcb-1.kicad_pcb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]
2026-10-07 Ordered Boards From OshPark for Rev D4
    [L1IFCape-B_Cu.gbr, L1IFCape-B_Mask.gbr, L1IFCape-B_Silkscreen.gbr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]

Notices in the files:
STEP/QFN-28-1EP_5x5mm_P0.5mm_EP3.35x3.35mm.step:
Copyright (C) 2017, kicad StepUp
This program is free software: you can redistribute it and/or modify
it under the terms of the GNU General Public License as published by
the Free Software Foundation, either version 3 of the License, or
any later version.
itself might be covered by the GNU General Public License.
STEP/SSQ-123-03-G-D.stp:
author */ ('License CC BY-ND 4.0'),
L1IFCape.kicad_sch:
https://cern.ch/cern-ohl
